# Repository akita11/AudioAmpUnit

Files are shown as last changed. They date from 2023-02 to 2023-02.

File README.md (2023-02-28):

# AudioAmpUnit

Heroic社のオーディオアンプHT8693を使った10Wクラスのオーディオアンプです。（※電源電圧5Vでは3W程度） Groveコネクタからのオーディオ信号を、つないだスピーカで鳴らすことができます。イネーブル端子もGroveから制御できます。M5StackでDAC出力が使いやすいようなピン配置です。スピーカ接続端子の形状で2種類あります（プリント基板自体は両者で同一です）。なおGrove端子のピン配置は「Enable/AudioIn/VDD/GND」の順ですが、オーディオ入力とイネーブル信号の配置をソルダージャンパで入れ替え可能です。

いずれも、AudioIn信号に再生したい音声信号の電圧振幅をDAC出力から与えてください。Enabe=1とすればアンプがONとなり、Enable=0でアンプはOFFとなります。Enable信号は30kΩでプルアップされているので、未接続時・未使用時（マイコン側を入力端子に設定した場合など）にはアンプはONとなります。

## AudioAmpUnit（3.5mmJack)

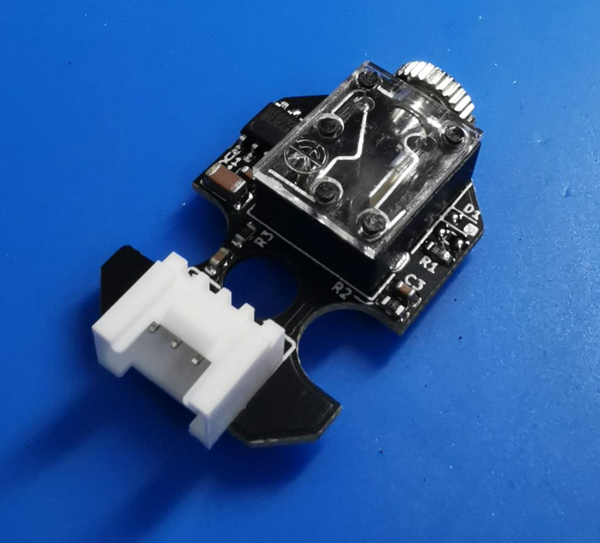
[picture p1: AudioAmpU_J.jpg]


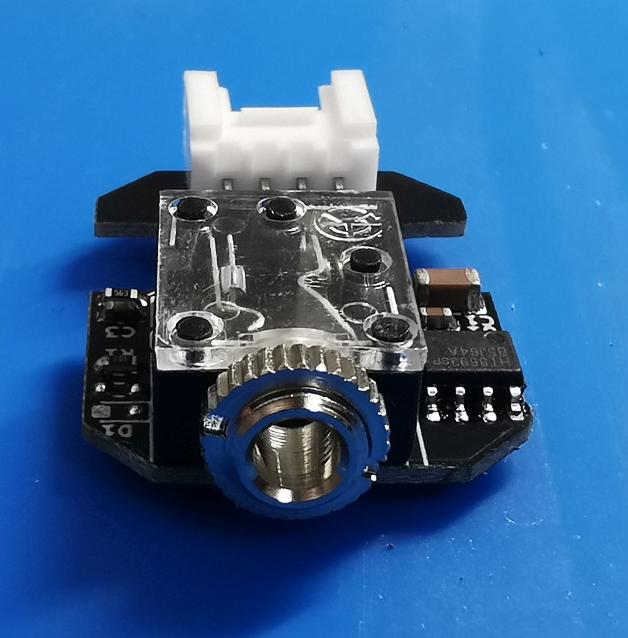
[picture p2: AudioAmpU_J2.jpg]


φ3.5mmプラグのついたスピーカを接続可能です。ステレオスピーカではL側のみから出力されます。

## AudioAmpUnit（ねじ端子）

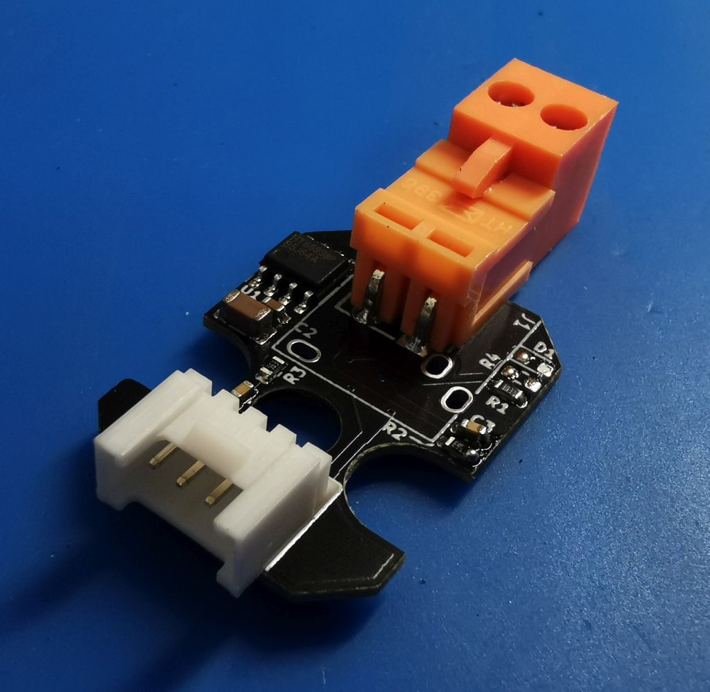
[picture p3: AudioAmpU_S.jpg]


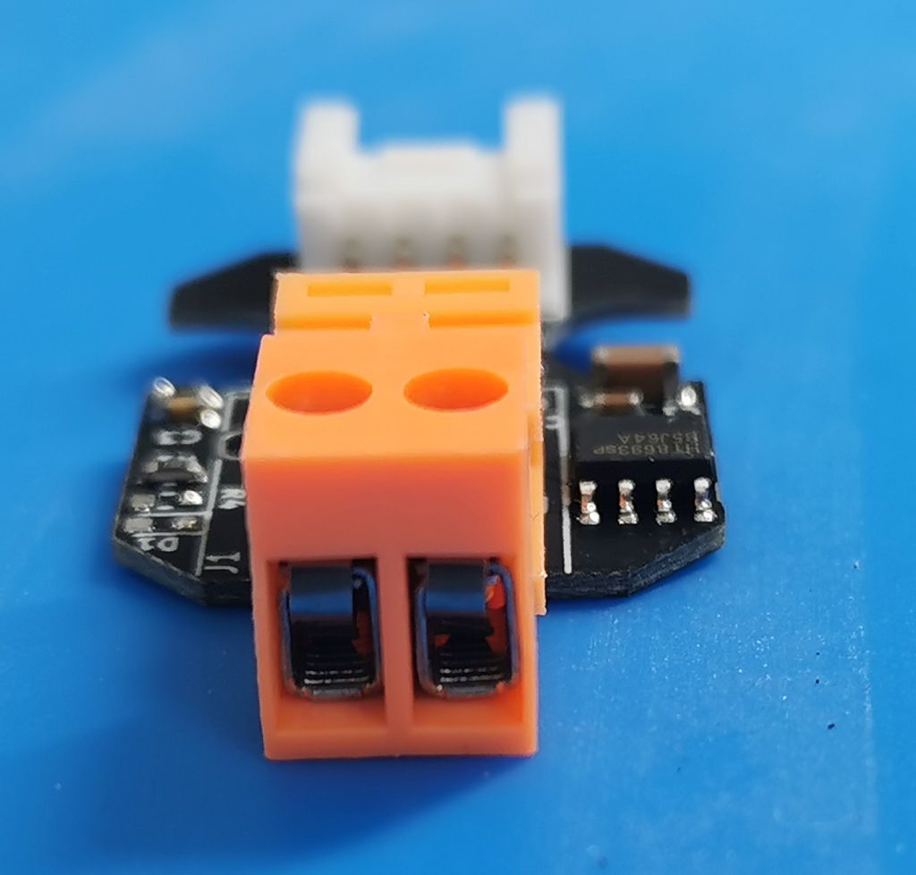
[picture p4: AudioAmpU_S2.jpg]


ねじ端子（VH3.96コネクタ）にスピーカを接続して使います。

基板形状が「[M5Stack用ADCユニット[U013]](https://www.switch-science.com/products/5221)」等と同一のため、そのケースを使うことができます。

## 設定の変更

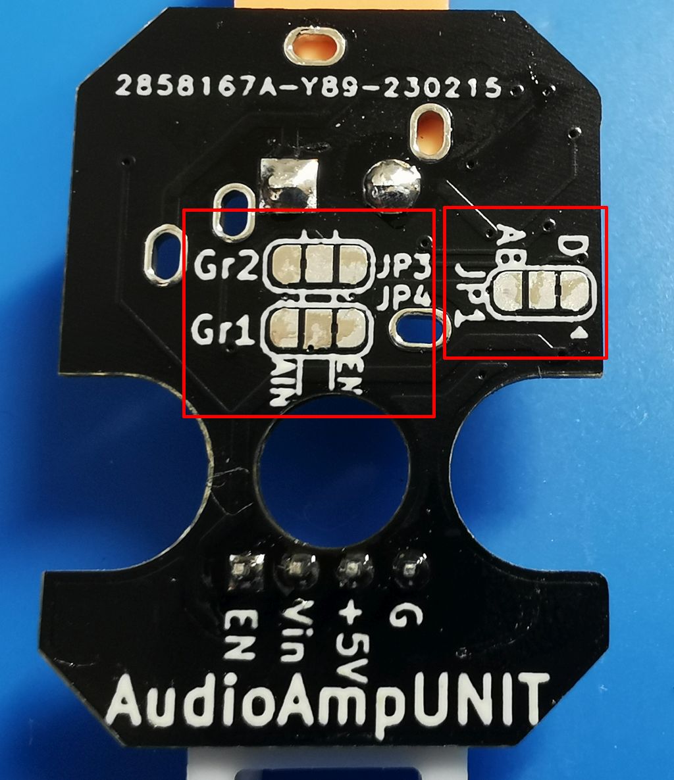
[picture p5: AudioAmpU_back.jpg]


- 動作モード: JP1を、中央-「D」をショート（デフォルトで基板パターンでショート）＝D級動作、中央-「AB」をショート＝AB級動作（D側の基板パターンをカットしてから使ってください）
- Groveコネクタのピン割当：JP3=Grove1番ピン(Gr1)。中央-「EN」（デフォルト）=Enable、中央-「AIN」=AudioIn（EN側の基板パターンをカットしてから使ってください）
- Groveコネクタのピン割当：JP4=Grove2番ピン(Gr2)。中央-「AIN」（デフォルト）=AudioIn、中央-「EN」=Enable（AudioIn側の基板パターンをカットしてから使ってください）

## Author

Junichi Akita (akita@ifdl.jp, @akita11)

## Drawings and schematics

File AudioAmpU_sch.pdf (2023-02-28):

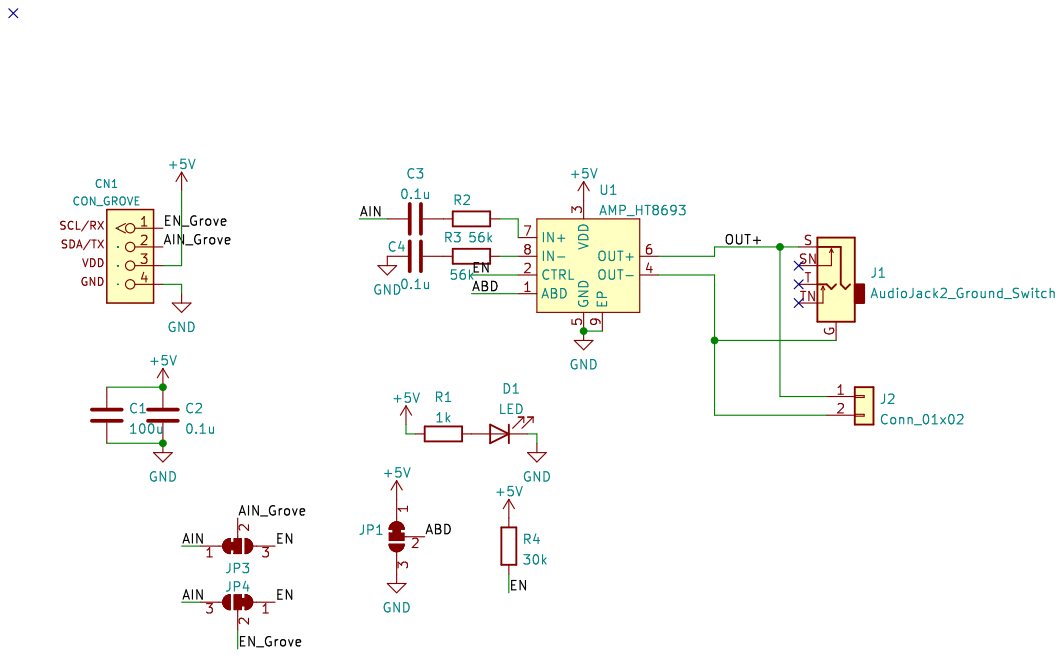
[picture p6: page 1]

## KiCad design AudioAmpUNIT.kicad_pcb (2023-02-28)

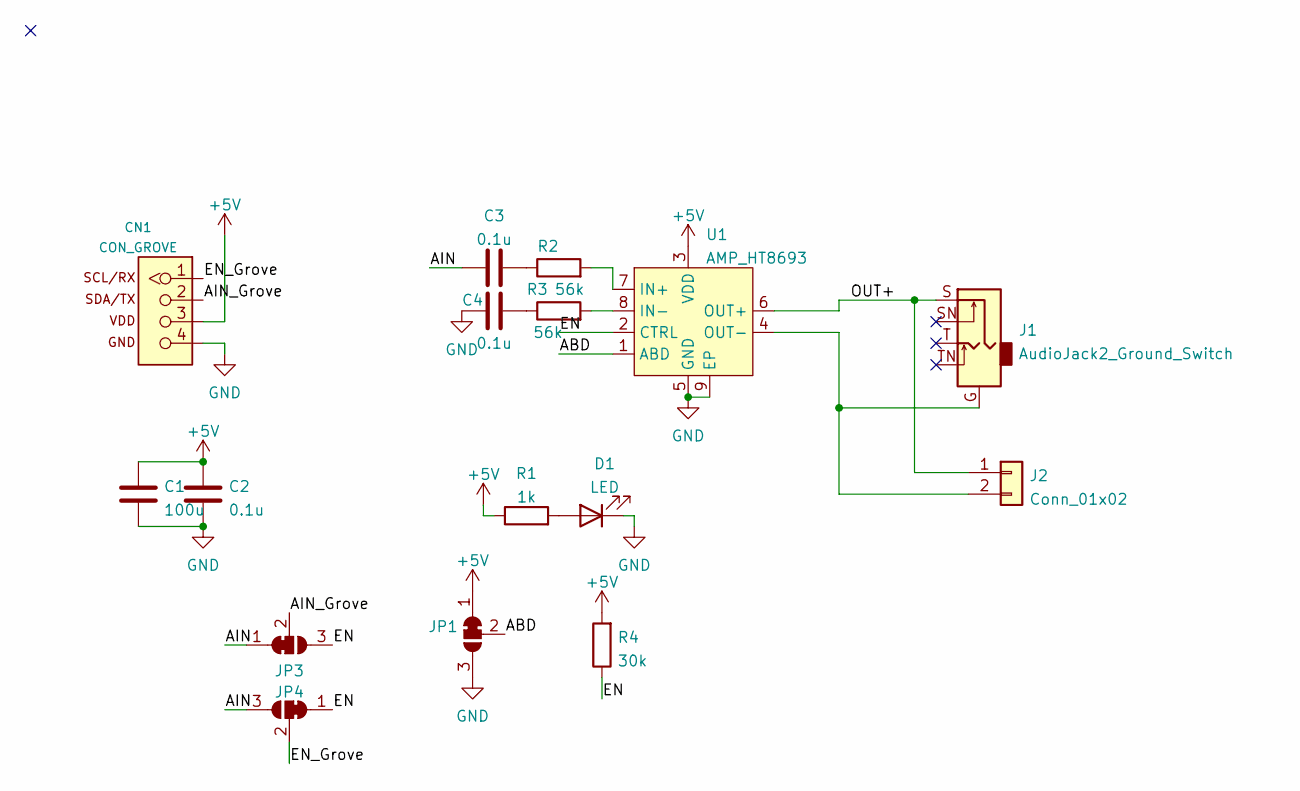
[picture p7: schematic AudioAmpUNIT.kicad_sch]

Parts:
C1: 100u; C_1206_3216Metric
C2, C3, C4: 0.1u; C_0603_1608Metric
CN1: CON_GROVE; CON_GROVE_H
D1: LED; LED_0603_1608Metric
J1: AudioJack2_Ground_Switch; CON_AJ-1780
J2: Conn_01x02; CON_HT396R_2P
JP1, JP3, JP4: SolderJumper_3_Bridged12; SolderJumper-3_P1.3mm_Bridged2Bar12_RoundedPad1.0x1.5mm
R1: 1k; R_0603_1608Metric
R2, R3: 56k; R_0603_1608Metric
R4: 30k; R_0603_1608Metric
U1: AMP_HT8693; SOP-8-EP_3.9x4.9mm_P1.27mm

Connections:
+5V: C1.2, C2.2, CN1.3, JP1.1 (A), R1.1, R4.2, U1.3 (VDD)
/ABD: JP1.2 (C), U1.1 (ABD)
/AIN: C3.1, JP3.1 (A), JP4.3 (B)
/AIN_Grove: CN1.2, JP3.2 (C)
/EN: JP3.3 (B), JP4.1 (A), R4.1, U1.2 (CTRL)
/EN_Grove: CN1.1, JP4.2 (C)
/OUT+: J1.S, J2.1, U1.6 (OUT+)
GND: C1.1, C2.1, C4.1, CN1.4, D1.1 (K), JP1.3 (B), U1.5 (GND), U1.9 (EP)
unnamed: C3.2, R2.1
unnamed: C4.2, R3.1
unnamed: D1.2 (A), R1.2
unnamed: J1.G, J2.2, U1.4 (OUT-)
unnamed: R2.2, U1.7 (IN+)
unnamed: R3.2, U1.8 (IN-)

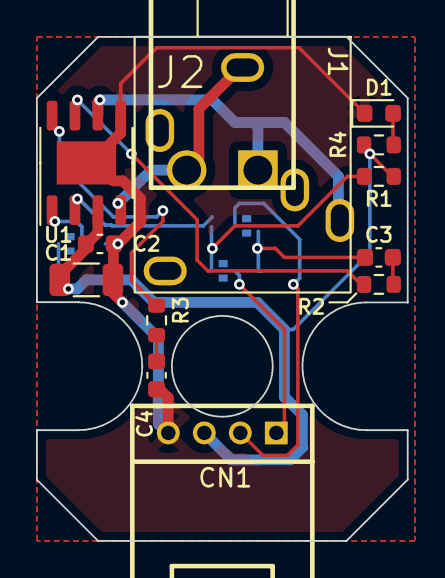
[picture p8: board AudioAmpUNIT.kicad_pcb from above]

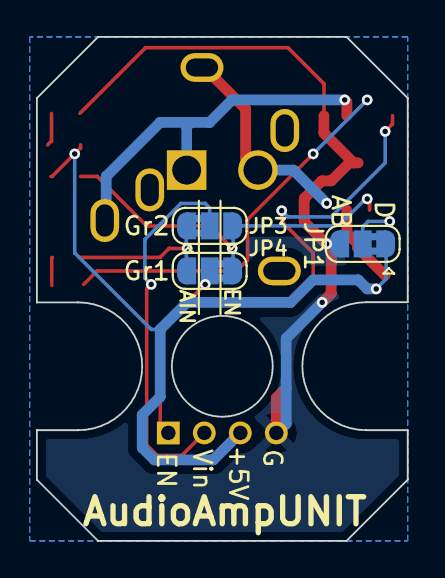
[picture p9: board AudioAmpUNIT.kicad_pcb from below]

Board: 2 copper layers, 20.6 x 28.0 mm, 16 parts (3 on the bottom side), 14 nets.

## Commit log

2023-02-28 add schematic
2023-02-28 add KiCAD files
    [AudioAmpUNIT.kicad_pcb, AudioAmpUNIT.kicad_sch]
